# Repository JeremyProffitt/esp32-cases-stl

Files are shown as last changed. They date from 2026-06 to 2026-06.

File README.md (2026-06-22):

# ESP32 Cases (OpenSCAD / STL)

OpenSCAD designs for 3D-printable ESP32 device enclosures.

Generated STL and PNG artifacts are **not committed** — they are produced by
the build scripts and attached to [GitHub Releases](https://github.com/JeremyProffitt/esp32-cases-stl/releases/latest).

## Building locally

Requires [OpenSCAD](https://openscad.org/). Then:

```bash
./build.sh        # Linux / macOS
build.bat         # Windows
```

This renders an STL plus front/rear PNGs for **every** `.scad` in the repo into
`build/`.

---

## Designs

### TTGO-TM ESP32 ("TMusic") Enclosure

A two-part enclosure for a TTGO-TM ESP32 music device: a **base tray** (the
deep box that holds the PCB) and a **front bezel** (the face with the display
window, speaker/finger slots, button hole and side ports). Footprint
76.2 × 49.5 mm.

Each part is provided in **two forms**:

- **Mesh wrapper** (`*_mesh.scad`) — imports the original CATIA-exported STL
  verbatim. **Geometry-exact**; use for final prints / fit checks.
- **Parametric rebuild** (`ttgo_body.scad`, `ttgo_cap.scad`) — hand-modelled
  from OpenSCAD primitives. **Editable but approximate**; use to tweak
  dimensions.

Folder: [`TTGO-TM-ESP32-aka-TMusic/`](TTGO-TM-ESP32-aka-TMusic/)

#### Drawing diagrams

Dimensioned multi-view (front / top / right / isometric) engineering sheets,
generated from the parametric models by [`tools/make_drawings.py`](tools/make_drawings.py):

| Base Tray | Front Bezel |
|---|---|
| Tray drawing | Bezel drawing |

#### Base Tray — parametric (`ttgo_cap.scad`)

| Front View | Rear View |
|---|---|
| Front | Rear |

**Documentation**: [ttgo_cap.md](TTGO-TM-ESP32-aka-TMusic/ttgo_cap.md)
· **Download STL**: [ttgo_cap.stl](https://github.com/JeremyProffitt/esp32-cases-stl/releases/latest/download/ttgo_cap.stl)

#### Base Tray — exact mesh (`ttgo_cap_mesh.scad`)

| Front View | Rear View |
|---|---|
| Front | Rear |

**Documentation**: [ttgo_cap_mesh.md](TTGO-TM-ESP32-aka-TMusic/ttgo_cap_mesh.md)
· **Download STL**: [ttgo_cap_mesh.stl](https://github.com/JeremyProffitt/esp32-cases-stl/releases/latest/download/ttgo_cap_mesh.stl)

#### Front Bezel — parametric (`ttgo_body.scad`)

| Front View | Rear View |
|---|---|
| Front | Rear |

**Documentation**: [ttgo_body.md](TTGO-TM-ESP32-aka-TMusic/ttgo_body.md)
· **Download STL**: [ttgo_body.stl](https://github.com/JeremyProffitt/esp32-cases-stl/releases/latest/download/ttgo_body.stl)

#### Front Bezel — exact mesh (`ttgo_body_mesh.scad`)

| Front View | Rear View |
|---|---|
| Front | Rear |

**Documentation**: [ttgo_body_mesh.md](TTGO-TM-ESP32-aka-TMusic/ttgo_body_mesh.md)
· **Download STL**: [ttgo_body_mesh.stl](https://github.com/JeremyProffitt/esp32-cases-stl/releases/latest/download/ttgo_body_mesh.stl)

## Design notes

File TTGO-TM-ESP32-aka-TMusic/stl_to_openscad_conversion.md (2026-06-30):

# STL To OpenSCAD Conversion Notes

## Purpose

This document records how the TTGO-TM ESP32 ("TMusic") STL files in this folder
were converted into editable OpenSCAD approximations.

The goal was not to reproduce every triangle. STL files do not contain the
original CAD feature tree, sketch constraints, or boolean history. The practical
goal was to identify the functional envelope, openings, cavities, lips, rims,
and support features, then rebuild them with clean named OpenSCAD primitives.

## Files Converted

| Source STL | New Parametric SCAD | Functional Name |
|---|---|---|
| `ttgo-body-2.stl` | `ttgo_body.scad` | `ttgo_top_bezel()` |
| `ttgo-cap-2.stl` | `ttgo_cap.scad` | `ttgo_base_tray()` |

Backward-compatible module names were retained:

- `ttgo_body()` calls `ttgo_top_bezel()`.
- `ttgo_cap()` calls `ttgo_base_tray()`.

## Guidance Used

The process followed `C:\dev\esp32-cases-stl\CLAUDE.md`:

- Document the coordinate system at the top of each SCAD file.
- Use named `*_mm` constants for all measurements.
- Keep each component or cutout in its own module.
- Include a component index table.
- Add module comments with position, bounding box, alignment, and connection
  notes.
- Provide connection interface functions.
- Provide debug and validation modules.
- Keep matching Markdown documentation next to each SCAD file.

## Measurement Method

The STLs were inspected with Python `trimesh` and section plots:

```powershell
python - <<'PY'
import trimesh
for file in ["ttgo-body-2.stl", "ttgo-cap-2.stl"]:
    mesh = trimesh.load_mesh(file, process=True)
    print(file, len(mesh.faces), mesh.bounds, mesh.extents, mesh.is_watertight)
PY
```

Additional XY section images were generated at representative Z heights and
saved in `analysis_slices/`.

Measured source facts:

| Part | Faces | Native min [X,Y,Z] | Native max [X,Y,Z] | Size [W,D,H] |
|---|---|---|---|---|
| Top bezel | 51,684 | [-36.675, -44.4235, -3.540] | [39.525, 5.1000, 11.460] | [76.200, 49.5235, 15.000] |
| Base tray | 54,112 | [-36.675, -44.4235, -20.290] | [39.525, 5.1000, 1.860] | [76.200, 49.5235, 22.150] |

The earlier mesh Markdown had the face counts swapped; the docs now reflect the
actual loaded files.

## Coordinate Normalization

The original CATIA-exported meshes use native coordinates with the origin inside
or near the assembly. The parametric SCAD files use the project convention:

```text
X = width
Y = depth
Z = height
Origin = front-left-bottom corner of each normalized part
```

Normalization is:

```text
normalized_point = native_point - source_bbox_min
```

The validation modules reverse this by importing the STL and applying:

```openscad
translate(-source_*_bbox_min_mm)
    import(source_*_mesh_file, convexity = 10);
```

## Reconstruction Strategy

Each part was rebuilt using the same pattern:

1. Start with a positive rounded rectangular bounding block matching the STL
   length, width, and height.
2. Subtract named negative cutouts for cavities and openings.
3. Add positive support features only when they are functional and visible in
   multiple sections.
4. Preserve the exact STL import as a validation overlay, not as the default
   model.

This makes the SCAD files readable as manufacturing recipes instead of opaque
polyhedron dumps.

## Top Bezel Feature Decisions

The top bezel was rebuilt around these named features:

- `top_bezel_positive_shell()`: full `76.2 x 49.523 x 15 mm` rounded shell.
- `top_bezel_inner_cavity_cutout()`: underside cavity leaving a 3 mm top face.
- `top_bezel_display_window_cutout()`: large display aperture measured from
  high-Z sections, about `51.5 x 38.4 mm`.
- `top_bezel_side_control_slot_cutouts()`: four rounded rectangular openings.
- `top_bezel_corner_relief_hole_cutouts()`: four small 1.9 mm holes near the
  top-face corners.
- `top_bezel_skirt_alignment_relief_cutouts()`: small inside-wall lower skirt
  reliefs, now starting 3 mm above the bezel bottom.

Important correction: the previous approximation used five narrow slots. The
source mesh sections show four larger rounded slots, so the rebuild uses four.

## Base Tray Feature Decisions

The base tray was rebuilt around these named features:

- `base_tray_outer_block()`: full `76.2 x 49.523 x 22.15 mm` rounded shell.
- `base_tray_inner_cavity_cutout()`: main electronics cavity, starting above a
  1.75 mm floor.
- `base_tray_rim_rabbet_cutout()`: top perimeter rabbet, approximately 5.4 mm
  high, used by the bezel skirt.
- `base_tray_support_lugs_positive()`: four discrete lugs near the upper rim.
- `base_tray_snap_tabs_positive()`: positive tabs on the tray lip that align
  with the bezel's inside-wall snap relief pockets.
- `base_tray_left_wall_connector_relief_cutouts()`: two left-wall reliefs at
  the upper rim.

Important correction: the previous approximation used continuous PCB rails. The
source sections show discrete support/lug blocks, so the rebuild models those
instead.

## Validation Performed

OpenSCAD was found at:

```text
C:\Program Files\OpenSCAD\openscad.exe
```

Both files were exported through OpenSCAD:

```powershell
& 'C:\Program Files\OpenSCAD\openscad.exe' -o .\build\ttgo_body_test.stl .\ttgo_body.scad
& 'C:\Program Files\OpenSCAD\openscad.exe' -o .\build\ttgo_cap_test.stl .\ttgo_cap.scad
```

The generated STL files were then checked with `trimesh`:

| Generated STL | Watertight | Connected Components | Extents |
|---|---|---|---|
| `build/ttgo_body_test.stl` | yes | 1 | [76.2, 49.523, 15.0] |
| `build/ttgo_cap_test.stl` | yes | 1 | [76.2, 49.523, 22.15] |

Preview PNGs were also rendered with OpenSCAD:

```powershell
& 'C:\Program Files\OpenSCAD\openscad.exe' --autocenter --viewall --imgsize=1200,900 --camera=0,0,0,55,0,45,0 -o .\build\ttgo_body_preview.png .\ttgo_body.scad
& 'C:\Program Files\OpenSCAD\openscad.exe' --autocenter --viewall --imgsize=1200,900 --camera=0,0,0,55,0,45,0 -o .\build\ttgo_cap_preview.png .\ttgo_cap.scad
```

## How To Inspect In OpenSCAD

Open either file in OpenSCAD:

- `ttgo_body.scad`
- `ttgo_cap.scad`

At the bottom of each SCAD file, use:

```openscad
see_in_color = 1; // colored manual preview
```

Primary display toggle:

| Variable | Meaning |
|---|---|
| `see_in_color = 0` | Printable model view and STL export; forced by `build.sh` and `build.bat` |
| `see_in_color = 1` | Default manual view; color-coded positive/support/cutout preview for OpenSCAD Preview/F5 |

Advanced debug modes are available through `debug_view_mode` when
`see_in_color = 0`:

| Mode | Meaning |
|---|---|
| `"model"` | Default rebuilt parametric part for printable STL export |
| `"overlay"` | Rebuilt part over the normalized source STL |
| `"cutouts"` | Positive shell plus visible negative volumes |
| `"positive"` | Positive starting geometry only |
| `"section_x"` | Thin X section |
| `"section_y"` | Thin Y section |

## Remaining Judgment Calls

The following details should be verified against the real board before final
printing:

- Whether the four small top holes are screw holes, locating holes, or reliefs.
- Exact connector clearance needs on the left wall and lower skirt.
- Whether the support lugs should be widened or lowered for the actual PCB.
- Preferred fit clearance between the bezel skirt and base tray rim.

## Summary

The final SCAD files are now editable constructive models instead of mesh
imports or polyhedron dumps. The source STLs remain available through the mesh
wrapper files for exact reference and overlay validation.

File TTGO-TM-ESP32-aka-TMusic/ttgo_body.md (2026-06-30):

# TTGO-TM ESP32 ("TMusic") - Top / Front Bezel

## Overview

`ttgo_body.scad` is an editable, constructive OpenSCAD rebuild of
`ttgo-body-2.stl`. It is not a triangle-exact copy. The source STL remains the
fit-check reference; this model turns the measured STL envelope and visible
openings into named positive and negative primitives.

The model starts with a positive rounded bounding shell and removes named
negative cutouts for the underside cavity, display window, four side control
slots, four small corner relief holes, and skirt alignment reliefs.

## Source Mesh

| Property | Value |
|---|---|
| File | `ttgo-body-2.stl` |
| Faces | 51,684 |
| Native min [X,Y,Z] mm | [-36.675, -44.4235, -3.540] |
| Native max [X,Y,Z] mm | [39.525, 5.1000, 11.460] |
| Normalized size [W,D,H] mm | [76.200, 49.5235, 15.000] |

The SCAD file uses normalized corner-origin coordinates. The validation overlay
imports the mesh and translates it by `-source_body_bbox_min_mm`.

## Coordinate System

```text
X = Width  (positive = right)
Y = Depth  (positive = back/away from viewer)
Z = Height (positive = up)

Origin: front-left-bottom corner of the normalized bezel bounding box.
```

## Dimensions

| Parameter | Value | Description |
|---|---|---|
| **Source** | | |
| source_body_face_count | 51684 | STL face count from `trimesh` and OpenSCAD import checks |
| source_body_bbox_size_mm | [76.200, 49.5235, 15.000] | Mesh bounding-box size |
| **Global / Shared** | | |
| case_width_mm | 76.200 | Overall X envelope |
| case_depth_mm | 49.523 | Overall Y envelope |
| case_corner_radius_mm | 2.300 | Clean outer corner radius |
| case_inner_corner_radius_mm | 1.300 | Inner cavity corner radius |
| case_wall_thickness_mm | 2.500 | Nominal wall thickness target |
| case_fit_clearance_xy_mm | 0.250 | Named fit allowance for mating interfaces |
| case_epsilon_mm | 0.050 | Boolean anti-coincident-face offset |
| **top_bezel_positive_shell** | | |
| top_bezel_height_mm | 15.000 | Overall Z height |
| top_bezel_face_thickness_mm | 3.000 | Top face plate thickness |
| top_bezel_skirt_height_mm | 12.000 | Lower skirt height |
| **top_bezel_inner_cavity_cutout** | | |
| top_bezel_inner_cavity_x_mm | 2.900 | Cavity X origin |
| top_bezel_inner_cavity_y_mm | 2.400 | Cavity Y origin |
| top_bezel_inner_cavity_width_mm | 70.400 | Cavity X size |
| top_bezel_inner_cavity_depth_mm | 44.700 | Cavity Y size |
| **top_bezel_display_window_cutout** | | |
| display_window_x_mm | 15.200 | Window X origin |
| display_window_y_mm | 5.600 | Window Y origin |
| display_window_width_mm | 51.500 | Window X size |
| display_window_depth_mm | 38.400 | Window Y size |
| display_window_corner_radius_mm | 0.800 | Clean corner radius |
| **top_bezel_side_control_slot_cutouts** | | |
| side_control_slot_count | 4 | Number of rounded side slots observed in top slices |
| side_control_slot_x_mm | 2.750 | Slot X origin |
| side_control_slot_first_y_mm | 12.100 | First slot Y origin |
| side_control_slot_pitch_mm | 7.600 | Y pitch |
| side_control_slot_width_mm | 8.700 | Slot X size |
| side_control_slot_depth_mm | 5.900 | Slot Y size |
| side_control_slot_radius_mm | 2.700 | Slot end radius |
| **top_bezel_corner_relief_hole_cutouts** | | |
| corner_relief_hole_diameter_mm | 1.900 | Small relief hole diameter |
| corner_relief_hole_left_x_mm / right_x_mm | 6.200 / 70.850 | Hole X centers |
| corner_relief_hole_front_y_mm / back_y_mm | 5.300 / 44.350 | Hole Y centers |
| **top_bezel_skirt_alignment_relief_cutouts** | | |
| skirt_relief_width_mm | 8.000 | Front/back skirt notch width |
| skirt_relief_depth_mm | 1.400 | Front/back skirt notch depth |
| skirt_relief_height_mm | 2.500 | Lower skirt notch height |
| skirt_relief_z_mm | 3.000 | Relief bottom height above bezel bottom |

## Color Key

`see_in_color` defaults to `1` in `ttgo_body.scad`, so OpenSCAD Preview (`F5`)
shows the shell and cutout volumes by color when the file is opened manually.
Set `see_in_color = 0` for the printable boolean result; the project build
scripts force that value for generated STL/PNG artifacts. The cutouts are voids
in the printable model, so they cannot remain separately colored. Colors are
preview aids only; exported STL files do not retain them.

| Color | Section Name | Meaning |
|---|---|---|
| Gold | `top_bezel_positive_shell` | Starting positive bezel body |
| Dodger blue | `top_bezel_inner_cavity_cutout` | Underside hollow cavity removed from the shell |
| Lime green | `top_bezel_display_window_cutout` | Display window through-cut |
| Magenta | `top_bezel_side_control_slot_cutouts` | Four side control / access slots |
| Red | `top_bezel_corner_relief_hole_cutouts` | Four small corner relief holes |
| Cyan | `top_bezel_skirt_alignment_relief_cutouts` | Inside-wall lower skirt and side relief notches |
| Orange | `validation_source_mesh` | Source STL overlay in validation mode |

## Component Diagram

### Top View (looking down, -Z)

```text
        +Y (back)
           ^
    +--o---------------------------o--+
    | [slot]  +-------------------+   |
    | [slot]  |                   |   |
    | [slot]  |   display window  |   |
    | [slot]  |                   |   |
    |         +-------------------+   |
    +--o---------------------------o--+ --> +X
   /
  Origin [0,0]
```

### Side View (looking from right, -X)

```text
        +Z
         ^
    +----+------------------+  top face with window/slots/holes
    |                       |
    |       hollow skirt    |
    |                       |
    +---[small reliefs]-----+ --> +Y
   z=0
```

## Components

### top_bezel_positive_shell

- Purpose: Main printable mass of the top/front bezel.
- Position: Origin `[0,0,0]`.
- Bounding box: `[0,0,0]` to `[76.2,49.523,15]`.
- Construction: Rounded rectangular prism.

### top_bezel_inner_cavity_cutout

- Purpose: Opens the underside while preserving a 3 mm top face.
- Position: `[2.9,2.4,-0.05]`.
- Bounding box: approximately `[2.9,2.4,-0.05]` to `[73.3,47.1,12.05]`.

### top_bezel_display_window_cutout

- Purpose: Main display aperture.
- Position: `[15.2,5.6,11.95]`.
- Bounding box: approximately `[15.2,5.6,11.95]` to `[66.7,44.0,15.55]`.

### top_bezel_side_control_slot_cutouts

- Purpose: Four rounded rectangular side openings visible in upper mesh
  cross-sections.
- Position: left-side top face region.
- Approximate slot size: `[8.7,5.9,thru]`.

### top_bezel_corner_relief_hole_cutouts

- Purpose: Four small holes near the top-face corners. They are named
  generically because the STL does not reveal whether they are screw,
  locating, or manufacturing relief features.
- Diameter: `1.9 mm`.

### top_bezel_skirt_alignment_relief_cutouts

- Purpose: Small internal notches in the lower skirt and left slot wall region.
- Position: inside faces of the lower skirt walls, starting 3 mm above the
  bezel bottom.

## Debug And Validation Modules

| Module | Purpose |
|---|---|
| `debug_axes(length_mm)` | Shows RGB XYZ axes |
| `debug_bounds()` | Shows normalized bounding box |
| `debug_positive_only()` | Shows the starting positive shell |
| `debug_negative_only()` | Shows all cutout volumes |
| `debug_cutouts()` | Overlays positive shell and negative volumes |
| `color_key_preview()` | Shows the named color key geometry |
| `debug_section_x(x_mm)` | Thin X section |
| `debug_section_y(y_mm)` | Thin Y section |
| `validation_source_mesh()` | Imports and normalizes the source STL |
| `validation_overlay()` | Overlays rebuild and source mesh |
| `assembly_colored()` | Colored part view |
| `assembly_exploded(separation_mm)` | Exploded-position helper |

## Assembly Notes

- Mates with `ttgo_cap.scad` / `ttgo_base_tray()`.
- The original mesh and rebuild should be compared with `validation_overlay()`
  before printing.
- Print orientation depends on whether face quality or support avoidance matters
  more. Face-down gives a cleaner visible face; skirt-down reduces top-face bed
  contact marks but may need support for openings.
- Recommended material: PLA or PETG.

## Known Approximations

- Organic CATIA fillets were simplified to clean rounded rectangles.
- The four side slots are modeled from slice measurements rather than recovered
  CAD history.
- The lower skirt reliefs are functional approximations of repeated mesh edge
  breaks.

## Changelog

| Date | Change |
|---|---|
| 2026-06-30 | Rebuilt as explicit positive shell plus named negative cutouts; corrected slot count to four; added validation modules |

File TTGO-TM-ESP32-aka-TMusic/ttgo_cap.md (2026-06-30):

# TTGO-TM ESP32 ("TMusic") - Base Tray

## Overview

`ttgo_cap.scad` is an editable, constructive OpenSCAD rebuild of
`ttgo-cap-2.stl`. The source file name says "cap", but the part is the deep
base tray that holds the electronics and accepts the top/front bezel.

The model starts from the full positive bounding block, removes the main cavity
and rim rabbet as named negative cutouts, then adds discrete support/lug blocks
near the upper inner rim.

## Source Mesh

| Property | Value |
|---|---|
| File | `ttgo-cap-2.stl` |
| Faces | 54,112 |
| Native min [X,Y,Z] mm | [-36.675, -44.4235, -20.290] |
| Native max [X,Y,Z] mm | [39.525, 5.1000, 1.860] |
| Normalized size [W,D,H] mm | [76.200, 49.5235, 22.150] |

The SCAD file uses normalized corner-origin coordinates. The validation overlay
imports the mesh and translates it by `-source_cap_bbox_min_mm`.

## Coordinate System

```text
X = Width  (positive = right)
Y = Depth  (positive = back/away from viewer)
Z = Height (positive = up)

Origin: front-left-bottom corner of the normalized tray bounding box.
```

## Dimensions

| Parameter | Value | Description |
|---|---|---|
| **Source** | | |
| source_cap_face_count | 54112 | STL face count from `trimesh` and OpenSCAD import checks |
| source_cap_bbox_size_mm | [76.200, 49.5235, 22.150] | Mesh bounding-box size |
| **Global / Shared** | | |
| case_width_mm | 76.200 | Overall X envelope |
| case_depth_mm | 49.523 | Overall Y envelope |
| case_corner_radius_mm | 2.300 | Clean outer corner radius |
| case_inner_corner_radius_mm | 0.800 | Inner cavity corner radius |
| case_wall_thickness_mm | 2.500 | Nominal wall thickness target |
| case_fit_clearance_xy_mm | 0.250 | Per-side fit clearance |
| case_fit_clearance_z_mm | 0.200 | Seating clearance |
| case_epsilon_mm | 0.050 | Boolean anti-coincident-face offset |
| **base_tray_outer_block** | | |
| base_tray_height_mm | 22.150 | Overall tray height |
| base_tray_floor_thickness_mm | 1.750 | Floor thickness inferred from low-Z sections |
| **base_tray_inner_cavity_cutout** | | |
| base_tray_inner_cavity_x_mm | 5.250 | Cavity X origin |
| base_tray_inner_cavity_y_mm | 4.250 | Cavity Y origin |
| base_tray_inner_cavity_width_mm | 66.700 | Cavity X size |
| base_tray_inner_cavity_depth_mm | 41.000 | Cavity Y size |
| **base_tray_rim_rabbet_cutout** | | |
| base_tray_rim_height_mm | 5.400 | Upper rim/rabbet height |
| base_tray_rim_inset_x_mm | 3.700 | Inset rim X origin |
| base_tray_rim_inset_y_mm | 2.700 | Inset rim Y origin |
| base_tray_rim_width_mm | 69.800 | Inset rim X size |
| base_tray_rim_depth_mm | 44.100 | Inset rim Y size |
| **support_lugs** | | |
| support_lug_z_mm | 18.100 | Lug bottom Z |
| support_lug_height_mm | 3.300 | Lug height |
| support_lug_depth_mm | 2.200 | Lug Y protrusion |
| front_support_lug_specs_mm | [[13.8,14.2],[49.0,14.2]] | Front-side lug X origins and widths |
| rear_support_lug_specs_mm | [[23.8,6.4],[56.0,8.5]] | Rear-side lug X origins and widths |
| **base_tray_snap_tabs_positive** | | |
| snap_tab_relief_z_from_bezel_bottom_mm | 3.000 | Matching height of the bezel relief pockets |
| snap_tab_z_mm | 19.750 | Tab bottom Z on the tray rim |
| snap_tab_height_mm | 2.350 | Tab height after fit/top-clearance limiting |
| snap_tab_width_mm | 7.700 | Front/back tab X size with clearance |
| snap_tab_depth_mm | 1.250 | Front/back tab protrusion with clearance |
| snap_tab_left_width_mm | 1.650 | Left tab X protrusion with clearance |
| snap_tab_left_depth_mm | 3.500 | Left tab Y size with clearance |
| **base_tray_left_wall_connector_relief_cutouts** | | |
| left_wall_relief_centers_y_mm | [18.2,36.8] | Y centers for left wall reliefs |
| left_wall_relief_width_mm | 4.000 | X cut depth through left wall |
| left_wall_relief_depth_mm | 7.200 | Y relief size |
| left_wall_relief_height_mm | 8.500 | Z relief size |

## Color Key

`see_in_color` defaults to `1` in `ttgo_cap.scad`, so OpenSCAD Preview (`F5`)
shows the shell, support lugs, snap tabs, and cutout volumes by color when the
file is opened manually. Set `see_in_color = 0` for the printable boolean
result; the project build scripts force that value for generated STL/PNG
artifacts. The cutouts are voids in the printable model, so they cannot remain
separately colored. The magenta support lugs and cyan snap tabs are lifted
upward only in this preview mode so they are not hidden by the rim/cutout
volumes. Colors are preview aids only; exported STL files do not retain them.

| Color | Section Name | Meaning |
|---|---|---|
| Gold | `base_tray_outer_block` | Starting positive tray body |
| Dodger blue | `base_tray_inner_cavity_cutout` | Main electronics cavity removed from the tray |
| Lime green | `base_tray_rim_rabbet_cutout` | Rim rabbet removed to form the bezel seat |
| Magenta | `base_tray_support_lugs_positive` | Positive support / latch / PCB-location lugs |
| Cyan | `base_tray_snap_tabs_positive` | Positive snap tabs that fit the bezel inside-wall relief pockets |
| Red | `base_tray_left_wall_connector_relief_cutouts` | Upper left-wall connector relief cutouts |
| Orange | `validation_source_mesh` | Source STL overlay in validation mode |

## Component Diagram

### Top View (looking down, -Z, into the open tray)

```text
        +Y (back)
           ^
    +------+---------------------------+
    |     [rear lug]        [rear lug] |
    |  +-----------------------------+ |
    |  |                             | |
    |  |        inner cavity         | |
    |  |                             | |
    |  +-----------------------------+ |
    |   [front lug]       [front lug]  |
    +--[relief]-----------[relief]-----+ --> +X
   /
  Origin [0,0]
```

### Side View (looking from right, -X)

```text
        +Z
         ^
    +----+---------+  inset upper rim / rabbet
    |    cavity    |
    |              |
    |              |
    +--------------+
    |    floor     |
    +--------------+ --> +Y
   z=0
```

## Components

### base_tray_outer_block

- Purpose: Overall positive rounded bounding block.
- Position: Origin `[0,0,0]`.
- Bounding box: `[0,0,0]` to `[76.2,49.523,22.15]`.

### base_tray_inner_cavity_cutout

- Purpose: Main hollow electronics volume.
- Position: `[5.25,4.25,1.75]`.
- Bounding box: approximately `[5.25,4.25,1.75]` to `[71.95,45.25,22.65]`.

### base_tray_rim_rabbet_cutout

- Purpose: Removes the outer top ring to form the inset ledge that receives
  the bezel skirt.
- Z range: approximately `[16.75,22.15]`.
- Functional interface: `base_tray_rim_seat_size_mm()`.

### base_tray_support_lugs_positive

- Purpose: Four discrete support/latch/PCB-locating pads near the upper rim.
- Z range: `[18.1,21.4]`.
- These replace the earlier single continuous rail approximation.

### base_tray_snap_tabs_positive

- Purpose: Positive snap tabs on the tray lip that fit into the cyan
  inside-wall relief pockets in `ttgo_body.scad`.
- Position: front, back, and left rim lips.
- Z range: approximately `[19.75,22.10]`, matching relief pockets that start
  3 mm above the seated bezel bottom.
- Fit: tabs are slightly smaller than the bezel pockets using
  `snap_tab_clearance_xy_mm` and `snap_tab_clearance_z_mm`.

### base_tray_left_wall_connector_relief_cutouts

- Purpose: Two upper left-wall reliefs visible in high-Z source sections.
- These are modeled as clean rectangular cutouts because the STL does not
  expose original CAD feature history.

## Debug And Validation Modules

| Module | Purpose |
|---|---|
| `debug_axes(length_mm)` | Shows RGB XYZ axes |
| `debug_bounds()` | Shows normalized bounding box |
| `debug_positive_only()` | Shows the outer block plus lug positives |
| `debug_negative_only()` | Shows all cutout volumes |
| `debug_cutouts()` | Overlays positive and negative volumes |
| `color_key_preview()` | Shows the named color key geometry |
| `debug_section_x(x_mm)` | Thin X section |
| `debug_section_y(y_mm)` | Thin Y section |
| `validation_source_mesh()` | Imports and normalizes the source STL |
| `validation_overlay()` | Overlays rebuild and source mesh |
| `assembly_colored()` | Colored part view |
| `assembly_exploded(separation_mm)` | Exploded-position helper |

## Assembly Notes

- Mates with `ttgo_body.scad` / `ttgo_top_bezel()`.
- The rim seat includes named XY and Z clearances rather than hidden offsets.
- Print orientation: floor down, open mouth up.
- Recommended material: PLA or PETG.

## Known Approximations

- CATIA fillets and small organic transitions are simplified to clean radii.
- The rim/lug geometry is modeled from mesh slices, not recovered CAD history.
- Connector reliefs are named functionally but should be verified against the
  physical board before relying on them for final connector clearance.

## Changelog

| Date | Change |
|---|---|
| 2026-06-30 | Rebuilt as explicit constructive tray with rim rabbet, discrete support lugs, named reliefs, and validation modules |

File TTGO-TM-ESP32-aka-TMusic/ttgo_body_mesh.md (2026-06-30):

# TTGO-TM ESP32 ("TMusic") — Front Bezel (Mesh / Import Wrapper)

## Overview

Exact reproduction of the front bezel. [`ttgo_body_mesh.scad`](ttgo_body_mesh.scad)
imports the original CATIA-exported mesh **`ttgo-body-2.stl`** verbatim via
OpenSCAD's `import()`, so the geometry is 100 % faithful to the source part.

Use this file when you need the real geometry (final print, accurate fit
checks). For an editable parametric approximation, see
[`ttgo_body.scad`](ttgo_body.md).

> The source mesh must sit beside the `.scad` file (it does, in this folder).

## Source Mesh

| Property | Value |
|---|---|
| File | `ttgo-body-2.stl` |
| Generator | "STL generated by Digitized Shape Editor / CATIA" |
| Triangles | 51,684 |
| Min [X,Y,Z] mm | [-36.675, -44.423, -3.540] |
| Max [X,Y,Z] mm | [ 39.525, 5.100, 11.460] |
| Size [W,D,H] mm | [ 76.200, 49.523, 15.000] |

The mesh origin is interior to the part (CATIA digitised-shape origin), not at
a corner.

## Modules

| Module | Purpose |
|---|---|
| `ttgo_body_mesh()` | Import the bezel mesh as-is |
| `debug_axes(length)` | XYZ axes at origin |
| `debug_bounds()` | Transparent bounding box |
| `debug_recenter()` | Same mesh shifted so bbox-min sits at the origin |

## Notes

- `convexity = 10` is set so the preview renders correctly through the
  bezel's openings.
- Native coordinates are shared with `ttgo_cap_mesh.scad`; importing both in
  native coords shows them already mated.

## Changelog

| Date | Change |
|---|---|
| 2026-06-22 | Initial import wrapper for ttgo-body-2.stl |

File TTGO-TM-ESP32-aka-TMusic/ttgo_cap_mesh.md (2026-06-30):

# TTGO-TM ESP32 ("TMusic") — Base Tray (Mesh / Import Wrapper)

## Overview

Exact reproduction of the base tray. [`ttgo_cap_mesh.scad`](ttgo_cap_mesh.scad)
imports the original CATIA-exported mesh **`ttgo-cap-2.stl`** verbatim via
OpenSCAD's `import()`, so the geometry is 100 % faithful to the source part.

> **Naming note:** the source file is called *cap*, but the part is the deep
> **base tray**, not a lid.

Use this file when you need the real geometry. For an editable parametric
approximation, see [`ttgo_cap.scad`](ttgo_cap.md).

> The source mesh must sit beside the `.scad` file (it does, in this folder).

## Source Mesh

| Property | Value |
|---|---|
| File | `ttgo-cap-2.stl` |
| Generator | "STL generated by Digitized Shape Editor / CATIA" |
| Triangles | 54,112 |
| Min [X,Y,Z] mm | [-36.675, -44.423, -20.290] |
| Max [X,Y,Z] mm | [ 39.525, 5.100, 1.860] |
| Size [W,D,H] mm | [ 76.200, 49.523, 22.150] |

## Modules

| Module | Purpose |
|---|---|
| `ttgo_cap_mesh()` | Import the tray mesh as-is |
| `debug_axes(length)` | XYZ axes at origin |
| `debug_bounds()` | Transparent bounding box |
| `debug_recenter()` | Same mesh shifted so bbox-min sits at the origin |
| `assembly_mesh()` | Tray + bezel meshes shown together in native coords |

## Notes

- `convexity = 10` is set so the preview renders correctly through the deep
  cavity.
- The cap (z −20.29 … 1.86) and the body (z −3.54 … 11.46) share the same X/Y
  datum and overlap near z ≈ 0, so `assembly_mesh()` shows the closed
  enclosure.

## Changelog

| Date | Change |
|---|---|
| 2026-06-22 | Initial import wrapper for ttgo-cap-2.stl |

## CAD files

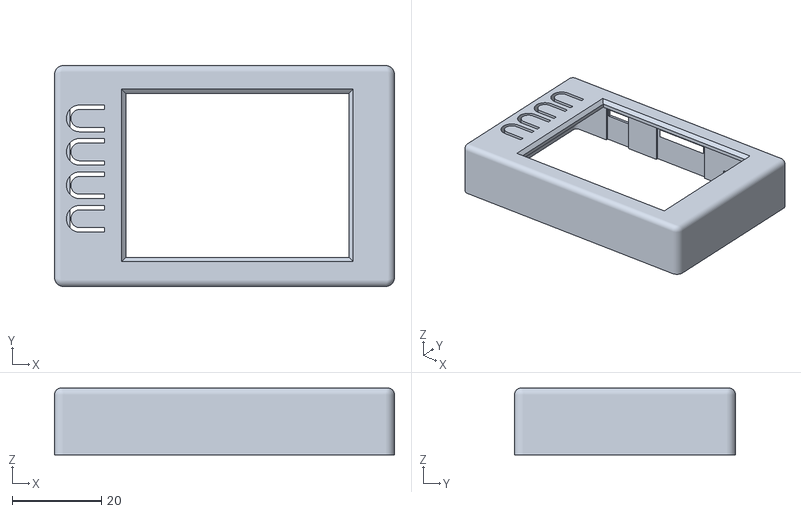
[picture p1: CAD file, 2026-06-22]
TTGO-TM-ESP32-aka-TMusic/ttgo-body-2.stl
76.2 x 49.5 x 15.0

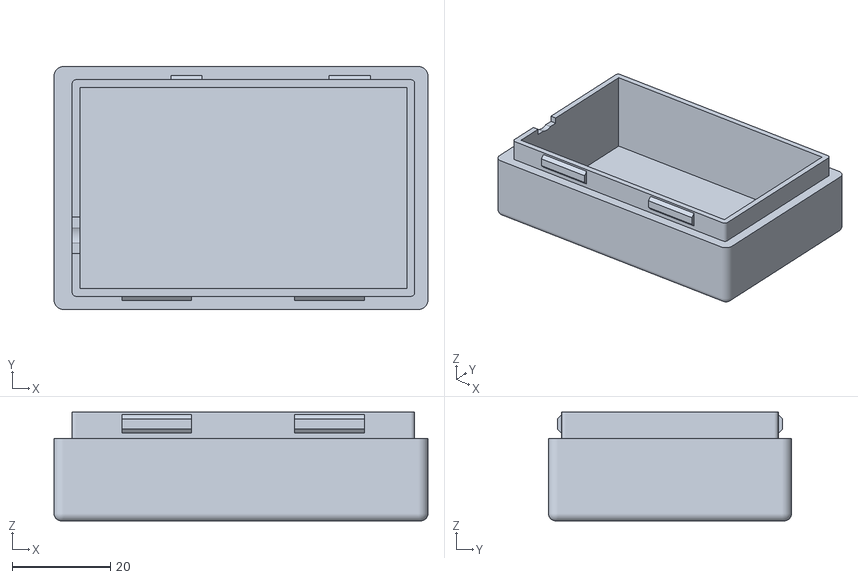
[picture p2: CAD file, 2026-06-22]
TTGO-TM-ESP32-aka-TMusic/ttgo-cap-2.stl
76.2 x 49.5 x 22.2

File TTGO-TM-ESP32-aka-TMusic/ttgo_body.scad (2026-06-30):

/**
 * TTGO-TM ESP32 ("TMusic") - TOP / FRONT BEZEL
 * Parametric constructive rebuild from ttgo-body-2.stl.
 *
 * This is an editable approximation, not a triangle-for-triangle copy. The
 * source STL is kept as the reference mesh. The model is built from one
 * positive rounded bounding shell and named negative cutouts for the functional
 * openings observed in mesh cross-sections.
 *
 * Coordinate System:
 *   X = Width  (positive = right)
 *   Y = Depth  (positive = back/away from viewer)
 *   Z = Height (positive = up)
 *
 * Origin: Front-left-bottom corner of the normalized bezel bounding box.
 *
 * ===========================================
 * COMPONENT INDEX
 * ===========================================
 *
 * | Component                    | Preview Color | Origin [X,Y,Z] | Size [W,D,H]       | Attaches To      |
 * |------------------------------|---------------|----------------|--------------------|------------------|
 * | top_bezel_positive_shell     | gold          | [0,0,0]        | [76.2,49.523,15]   | base tray rim    |
 * | top_bezel_inner_cavity       | dodgerblue    | [2.9,2.4,0]    | [70.4,44.7,12.05]  | negative cutout  |
 * | display_window               | limegreen     | [15.2,5.6,12]  | [51.5,38.4,thru]   | negative cutout  |
 * | side_control_slots (x4)      | magenta       | left face area | [8.7,5.9,thru]     | negative cutout  |
 * | corner_relief_holes (x4)     | red           | top corners    | d=1.9              | negative cutout  |
 * | skirt_alignment_reliefs      | cyan          | inside skirt walls | variable        | negative cutout  |
 */

// ===========================================
// DIMENSIONS (all values in millimeters)
// ===========================================

// --- Source mesh facts ---
source_body_mesh_file = "ttgo-body-2.stl";
source_body_bbox_min_mm = [-36.675, -44.4235, -3.540];
source_body_bbox_max_mm = [ 39.525,   5.1000, 11.460];
source_body_bbox_size_mm = [76.200, 49.5235, 15.000];
source_body_face_count = 51684;

// --- Global / shared case dimensions ---
case_width_mm = 76.200;
case_depth_mm = 49.523;
case_corner_radius_mm = 2.300;
case_inner_corner_radius_mm = 1.300;
case_wall_thickness_mm = 2.500;
case_fit_clearance_xy_mm = 0.250;
case_epsilon_mm = 0.050;
case_cut_overshoot_mm = 0.500;

// --- top_bezel_positive_shell dimensions ---
top_bezel_height_mm = 15.000;
top_bezel_face_thickness_mm = 3.000;
top_bezel_skirt_height_mm = top_bezel_height_mm - top_bezel_face_thickness_mm;

// --- top_bezel_inner_cavity_cutout dimensions ---
top_bezel_inner_cavity_x_mm = 2.900;
top_bezel_inner_cavity_y_mm = 2.400;
top_bezel_inner_cavity_width_mm = 70.400;
top_bezel_inner_cavity_depth_mm = 44.700;
top_bezel_inner_cavity_height_mm = top_bezel_skirt_height_mm + case_epsilon_mm;

// --- top_bezel_display_window_cutout dimensions ---
display_window_x_mm = 15.200;
display_window_y_mm = 5.600;
display_window_width_mm = 51.500;
display_window_depth_mm = 38.400;
display_window_corner_radius_mm = 0.800;

// --- top_bezel_side_control_slot_cutouts dimensions ---
side_control_slot_count = 4;
side_control_slot_x_mm = 2.750;
side_control_slot_first_y_mm = 12.100;
side_control_slot_pitch_mm = 7.600;
side_control_slot_width_mm = 8.700;
side_control_slot_depth_mm = 5.900;
side_control_slot_radius_mm = 2.700;

// --- top_bezel_corner_relief_hole_cutouts dimensions ---
corner_relief_hole_diameter_mm = 1.900;
corner_relief_hole_left_x_mm = 6.200;
corner_relief_hole_right_x_mm = 70.850;
corner_relief_hole_front_y_mm = 5.300;
corner_relief_hole_back_y_mm = 44.350;

// --- top_bezel_skirt_alignment_relief_cutouts dimensions ---
skirt_relief_width_mm = 8.000;
skirt_relief_depth_mm = 1.400;
skirt_relief_height_mm = 2.500;
skirt_relief_z_mm = 3.000;
front_skirt_relief_centers_x_mm = [18.800, 38.700, 59.700];
back_skirt_relief_centers_x_mm = [18.800, 38.700, 59.700];
left_skirt_relief_width_mm = 1.800;
left_skirt_relief_depth_mm = 3.800;
left_skirt_relief_centers_y_mm = [15.000, 22.600, 30.200, 37.800];

// --- Preview colors (used only by debug/color-key render modes) ---
color_top_bezel_shell = "gold";
color_inner_cavity_cutout = "dodgerblue";
color_display_window_cutout = "limegreen";
color_side_control_slot_cutouts = "magenta";
color_corner_relief_hole_cutouts = "red";
color_skirt_alignment_relief_cutouts = "cyan";
color_source_mesh_overlay = "orange";

$fn = 64;

// ===========================================
// HELPERS
// ===========================================

module rounded_rect_2d(width_mm, depth_mm, radius_mm) {
    effective_radius_mm = min(radius_mm, min(width_mm, depth_mm) / 2);
    hull() {
        translate([effective_radius_mm, effective_radius_mm])
            circle(r = effective_radius_mm);
        translate([width_mm - effective_radius_mm, effective_radius_mm])
            circle(r = effective_radius_mm);
        translate([effective_radius_mm, depth_mm - effective_radius_mm])
            circle(r = effective_radius_mm);
        translate([width_mm - effective_radius_mm, depth_mm - effective_radius_mm])
            circle(r = effective_radius_mm);
    }
}

module rounded_box(width_mm, depth_mm, height_mm, radius_mm) {
    linear_extrude(height = height_mm)
        rounded_rect_2d(width_mm, depth_mm, radius_mm);
}

module rounded_slot_box(width_mm, depth_mm, height_mm, radius_mm) {
    linear_extrude(height = height_mm)
        rounded_rect_2d(width_mm, depth_mm, radius_mm);
}

// ===========================================
// POSITIVE GEOMETRY
// ===========================================

/**
 * Top Bezel Positive Shell
 *
 * POSITION:
 *   Origin: [0,0,0]
 *
 * BOUNDING BOX:
 *   Min: [0,0,0]
 *   Max: [76.2,49.523,15]
 *
 * ALIGNMENT:
 *   The normalized source mesh bounding-box minimum maps to this origin.
 *
 * CONNECTS TO:
 *   - ttgo_base_tray: lower skirt seats in the base tray rim.
 */
module top_bezel_positive_shell() {
    rounded_box(case_width_mm, case_depth_mm, top_bezel_height_mm,
                case_corner_radius_mm);
}

// ===========================================
// NEGATIVE CUTOUTS
// ===========================================

module top_bezel_negative_cutouts() {
    top_bezel_inner_cavity_cutout();
    top_bezel_display_window_cutout();
    top_bezel_side_control_slot_cutouts();
    top_bezel_corner_relief_hole_cutouts();
    top_bezel_skirt_alignment_relief_cutouts();
}

/**
 * Inner Cavity Cutout
 *
 * POSITION:
 *   Origin: [2.9,2.4,-0.05]
 *
 * BOUNDING BOX:
 *   Min: [2.9,2.4,-0.05]
 *   Max: [73.3,47.1,12.05]
 *
 * ALIGNMENT:
 *   Opens the underside while leaving the top face plate intact.
 *
 * CONNECTS TO:
 *   - base tray cavity through the mating skirt opening.
 */
module top_bezel_inner_cavity_cutout() {
    translate([top_bezel_inner_cavity_x_mm,
               top_bezel_inner_cavity_y_mm,
               -case_epsilon_mm])
        rounded_box(top_bezel_inner_cavity_width_mm,
                    top_bezel_inner_cavity_depth_mm,
                    top_bezel_inner_cavity_height_mm,
                    case_inner_corner_radius_mm);
}

/**
 * Display Window Cutout
 *
 * POSITION:
 *   Origin: [15.2,5.6,11.95]
 *
 * BOUNDING BOX:
 *   Min: [15.2,5.6,11.95]
 *   Max: [66.7,44.0,15.55]
 *
 * ALIGNMENT:
 *   Through-cut in the top face plate, measured from upper Z slices.
 *
 * CONNECTS TO:
 *   - display glass / visible screen area.
 */
module top_bezel_display_window_cutout() {
    translate([display_window_x_mm,
               display_window_y_mm,
               top_bezel_height_mm - top_bezel_face_thickness_mm - case_epsilon_mm])
        rounded_box(display_window_width_mm,
                    display_window_depth_mm,
                    top_bezel_face_thickness_mm + (2 * case_cut_overshoot_mm),
                    display_window_corner_radius_mm);
}

/**
 * Side Control Slot Cutouts
 *
 * POSITION:
 *   Four rounded rectangular openings near the left side of the top face.
 *
 * BOUNDING BOX:
 *   Each slot is approximately [8.7,5.9,thru].
 *
 * ALIGNMENT:
 *   Centers are spaced along Y using side_control_slot_pitch_mm.
 *
 * CONNECTS TO:
 *   - side button / speaker / finger-access region from the source mesh.
 */
module top_bezel_side_control_slot_cutouts() {
    for (slot_index = [0 : side_control_slot_count - 1]) {
        translate([side_control_slot_x_mm,
                   side_control_slot_first_y_mm + slot_index * side_control_slot_pitch_mm,
                   top_bezel_height_mm - top_bezel_face_thickness_mm - case_epsilon_mm])
            rounded_slot_box(side_control_slot_width_mm,
                             side_control_slot_depth_mm,
                             top_bezel_face_thickness_mm + (2 * case_cut_overshoot_mm),
                             side_control_slot_radius_mm);
    }
}
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

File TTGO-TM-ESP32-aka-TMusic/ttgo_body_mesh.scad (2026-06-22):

/**
 * TTGO-TM ESP32 ("TMusic") — FRONT BEZEL  [MESH / IMPORT WRAPPER]
 *
 * This file imports the original CATIA-exported STL mesh verbatim, so the
 * geometry is 100% faithful to the source part. Use this when you need an
 * exact reproduction (e.g. final print). For an editable, parametric
 * approximation of the same part, see ttgo_body.scad.
 *
 * Coordinate System (inherited from the source mesh — NOT the project corner
 * convention; the parametric file ttgo_body.scad uses the corner convention):
 *   X = Width  (positive = right)
 *   Y = Depth  (positive = back/away from viewer)
 *   Z = Height (positive = up)
 *
 * SOURCE MESH BOUNDING BOX (millimetres):
 *   Min:  [-36.675, -44.423, -3.540]
 *   Max:  [ 39.525,   5.100, 11.460]
 *   Size: [ 76.200,  49.523, 15.000]
 *
 * The mesh origin is roughly inside the part (CATIA digitised-shape origin),
 * not at a corner. debug_recenter() below shifts the part so its bounding-box
 * min sits at the origin if you prefer corner-origin coordinates.
 */

// ===========================================
// SOURCE FILE
// ===========================================
body_mesh_file = "ttgo-body-2.stl";   // must sit beside this .scad

// Bounding-box constants (from mesh analysis) — used by debug helpers.
body_mesh_min_mm  = [-36.675, -44.423, -3.540];
body_mesh_max_mm  = [ 39.525,   5.100, 11.460];
body_mesh_size_mm = [ 76.200,  49.523, 15.000];

// ===========================================
// PART
// ===========================================

/**
 * Front bezel, exactly as exported.
 * POSITION:     mesh-native (origin interior to part)
 * BOUNDING BOX: see body_mesh_min_mm / body_mesh_max_mm above
 */
module ttgo_body_mesh() {
    import(body_mesh_file, convexity = 10);
}

// ===========================================
// DEBUG / VISUALIZATION
// ===========================================

// Render coordinate axes at origin (length = 50mm).
module debug_axes(length = 50) {
    color("red")   cylinder(h = length, r = 1, $fn = 16);                 // Z
    color("green") rotate([0, 90, 0]) cylinder(h = length, r = 1, $fn = 16); // X
    color("blue")  rotate([-90, 0, 0]) cylinder(h = length, r = 1, $fn = 16); // Y
}

// Transparent bounding box of the imported mesh.
module debug_bounds() {
    color("yellow", 0.2)
        translate(body_mesh_min_mm)
            cube(body_mesh_size_mm);
}

// Same mesh, shifted so its bounding-box min sits at the origin
// (corner-origin convention used elsewhere in this project).
module debug_recenter() {
    translate(-body_mesh_min_mm)
        ttgo_body_mesh();
}

// ===========================================
// DEFAULT RENDER
// ===========================================
ttgo_body_mesh();

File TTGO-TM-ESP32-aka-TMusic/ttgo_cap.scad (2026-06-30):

/**
 * TTGO-TM ESP32 ("TMusic") - BASE TRAY
 * Parametric constructive rebuild from ttgo-cap-2.stl.
 *
 * The source file uses "cap", but the part is the deep base tray. This model
 * starts with the overall rounded bounding block, removes the main cavity and
 * rim rabbet as named negative cutouts, and adds discrete support/lug blocks
 * observed in high-Z mesh cross-sections.
 *
 * Coordinate System:
 *   X = Width  (positive = right)
 *   Y = Depth  (positive = back/away from viewer)
 *   Z = Height (positive = up)
 *
 * Origin: Front-left-bottom corner of the normalized tray bounding box.
 *
 * ===========================================
 * COMPONENT INDEX
 * ===========================================
 *
 * | Component                     | Preview Color | Origin [X,Y,Z] | Size [W,D,H]        | Attaches To      |
 * |-------------------------------|---------------|----------------|---------------------|------------------|
 * | base_tray_outer_block         | gold          | [0,0,0]        | [76.2,49.523,22.15] | ground / print   |
 * | base_tray_inner_cavity        | dodgerblue    | [5.25,4.25,1.75]| [66.7,41.0,thru]   | negative cutout  |
 * | base_tray_rim_rabbet          | limegreen     | top perimeter  | 5.4 high            | bezel skirt      |
 * | support_lugs (x4)             | magenta       | inner rim      | variable            | PCB / latch area |
 * | snap_tabs                     | cyan          | rim lip        | variable            | bezel reliefs    |
 * | left_wall_connector_reliefs   | red           | left wall      | variable            | negative cutout  |
 */

// ===========================================
// DIMENSIONS (all values in millimeters)
// ===========================================

// --- Source mesh facts ---
source_cap_mesh_file = "ttgo-cap-2.stl";
source_cap_bbox_min_mm = [-36.675, -44.4235, -20.290];
source_cap_bbox_max_mm = [ 39.525,   5.1000,   1.860];
source_cap_bbox_size_mm = [76.200, 49.5235, 22.150];
source_cap_face_count = 54112;

// --- Global / shared case dimensions ---
case_width_mm = 76.200;
case_depth_mm = 49.523;
case_corner_radius_mm = 2.300;
case_inner_corner_radius_mm = 0.800;
case_wall_thickness_mm = 2.500;
case_fit_clearance_xy_mm = 0.250;
case_fit_clearance_z_mm = 0.200;
case_epsilon_mm = 0.050;
case_cut_overshoot_mm = 0.500;

// --- base_tray_outer_block dimensions ---
base_tray_height_mm = 22.150;
base_tray_floor_thickness_mm = 1.750;

// --- base_tray_inner_cavity_cutout dimensions ---
base_tray_inner_cavity_x_mm = 5.250;
base_tray_inner_cavity_y_mm = 4.250;
base_tray_inner_cavity_width_mm = 66.700;
base_tray_inner_cavity_depth_mm = 41.000;

// --- base_tray_rim_rabbet_cutout dimensions ---
base_tray_rim_height_mm = 5.400;
base_tray_rim_inset_x_mm = 3.700;
base_tray_rim_inset_y_mm = 2.700;
base_tray_rim_width_mm = 69.800;
base_tray_rim_depth_mm = 44.100;
base_tray_rim_corner_radius_mm = 1.600;

// --- support_lugs dimensions ---
support_lug_height_mm = 3.300;
support_lug_z_mm = 18.100;
support_lug_depth_mm = 2.200;
support_lug_corner_radius_mm = 0.400;
front_support_lug_specs_mm = [
    [13.800, 14.200],
    [49.000, 14.200]
];
rear_support_lug_specs_mm = [
    [23.800,  6.400],
    [56.000,  8.500]
];

// --- left_wall_connector_relief_cutouts dimensions ---
left_wall_relief_x_mm = -case_epsilon_mm;
left_wall_relief_width_mm = 4.000;
left_wall_relief_height_mm = 8.500;
left_wall_relief_z_mm = base_tray_height_mm - left_wall_relief_height_mm;
left_wall_relief_depth_mm = 7.200;
left_wall_relief_centers_y_mm = [18.200, 36.800];

// --- snap_tabs dimensions (positive tabs matching bezel inside-wall reliefs) ---
snap_tab_clearance_xy_mm = 0.150;
snap_tab_clearance_z_mm = 0.150;
snap_tab_relief_z_from_bezel_bottom_mm = 3.000;
snap_tab_z_mm = base_tray_height_mm - base_tray_rim_height_mm + snap_tab_relief_z_from_bezel_bottom_mm;
snap_tab_height_mm = min(2.500 - snap_tab_clearance_z_mm,
                         base_tray_height_mm - snap_tab_z_mm - case_epsilon_mm);
snap_tab_width_mm = 8.000 - 2 * snap_tab_clearance_xy_mm;
snap_tab_depth_mm = 1.400 - snap_tab_clearance_xy_mm;
snap_tab_front_centers_x_mm = [18.800, 38.700, 59.700];
snap_tab_back_centers_x_mm = [18.800, 38.700, 59.700];
snap_tab_left_width_mm = 1.800 - snap_tab_clearance_xy_mm;
snap_tab_left_depth_mm = 3.800 - 2 * snap_tab_clearance_xy_mm;
snap_tab_left_centers_y_mm = [15.000, 22.600, 30.200, 37.800];

// --- Preview colors (used only by debug/color-key render modes) ---
color_base_tray_outer_block = "gold";
color_inner_cavity_cutout = "dodgerblue";
color_rim_rabbet_cutout = "limegreen";
color_support_lugs = "magenta";
color_snap_tabs = "cyan";
color_left_wall_connector_reliefs = "red";
color_source_mesh_overlay = "orange";

$fn = 64;

// ===========================================
// HELPERS
// ===========================================

module rounded_rect_2d(width_mm, depth_mm, radius_mm) {
    effective_radius_mm = min(radius_mm, min(width_mm, depth_mm) / 2);
    hull() {
        translate([effective_radius_mm, effective_radius_mm])
            circle(r = effective_radius_mm);
        translate([width_mm - effective_radius_mm, effective_radius_mm])
            circle(r = effective_radius_mm);
        translate([effective_radius_mm, depth_mm - effective_radius_mm])
            circle(r = effective_radius_mm);
        translate([width_mm - effective_radius_mm, depth_mm - effective_radius_mm])
            circle(r = effective_radius_mm);
    }
}

module rounded_box(width_mm, depth_mm, height_mm, radius_mm) {
    linear_extrude(height = height_mm)
        rounded_rect_2d(width_mm, depth_mm, radius_mm);
}

// ===========================================
// POSITIVE GEOMETRY
// ===========================================

/**
 * Base Tray Outer Block
 *
 * POSITION:
 *   Origin: [0,0,0]
 *
 * BOUNDING BOX:
 *   Min: [0,0,0]
 *   Max: [76.2,49.523,22.15]
 *
 * ALIGNMENT:
 *   The normalized source mesh bounding-box minimum maps to this origin.
 *
 * CONNECTS TO:
 *   - top bezel skirt through the rim rabbet.
 */
module base_tray_outer_block() {
    rounded_box(case_width_mm, case_depth_mm, base_tray_height_mm,
                case_corner_radius_mm);
}

/**
 * Base Tray Support Lugs
 *
 * POSITION:
 *   Four discrete raised blocks near the upper inner rim.
 *
 * BOUNDING BOX:
 *   z range: [18.1,21.4].
 *
 * ALIGNMENT:
 *   The blocks are added after the cavity/rabbet are cut so they remain as
 *   functional pads inside the tray.
 *
 * CONNECTS TO:
 *   - PCB edge / bezel latch region inferred from source sections.
 */
module base_tray_support_lugs_positive() {
    for (lug_spec = front_support_lug_specs_mm) {
        translate([lug_spec[0],
                   base_tray_inner_cavity_y_mm - support_lug_depth_mm,
                   support_lug_z_mm])
            rounded_box(lug_spec[1],
                        support_lug_depth_mm,
                        support_lug_height_mm,
                        support_lug_corner_radius_mm);
    }

    for (lug_spec = rear_support_lug_specs_mm) {
        translate([lug_spec[0],
                   base_tray_inner_cavity_y_mm + base_tray_inner_cavity_depth_mm,
                   support_lug_z_mm])
            rounded_box(lug_spec[1],
                        support_lug_depth_mm,
                        support_lug_height_mm,
                        support_lug_corner_radius_mm);
    }
}

/**
 * Base Tray Snap Tabs
 *
 * POSITION:
 *   Positive tabs on the upper rim lip, aligned with the bezel's inside-wall
 *   skirt relief pockets.
 *
 * BOUNDING BOX:
 *   z range starts at snap_tab_z_mm, which places the tabs 3 mm above the
 *   seated bezel bottom.
 *
 * ALIGNMENT:
 *   Front/back tabs protrude outward from the tray rim lip. Left-side tabs
 *   protrude outward from the left rim lip. A small clearance is applied so the
 *   tabs fit into the bezel pockets instead of being the exact same size.
 *
 * CONNECTS TO:
 *   - top_bezel_skirt_alignment_relief_cutouts in ttgo_body.scad.
 */
module base_tray_snap_tabs_positive() {
    for (center_x_mm = snap_tab_front_centers_x_mm)
        translate([center_x_mm - snap_tab_width_mm / 2,
                   base_tray_rim_inset_y_mm - snap_tab_depth_mm,
                   snap_tab_z_mm])
            cube([snap_tab_width_mm,
                  snap_tab_depth_mm + case_epsilon_mm,
                  snap_tab_height_mm]);

    for (center_x_mm = snap_tab_back_centers_x_mm)
        translate([center_x_mm - snap_tab_width_mm / 2,
                   base_tray_rim_inset_y_mm + base_tray_rim_depth_mm - case_epsilon_mm,
                   snap_tab_z_mm])
            cube([snap_tab_width_mm,
                  snap_tab_depth_mm + case_epsilon_mm,
                  snap_tab_height_mm]);
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

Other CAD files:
TTGO-TM-ESP32-aka-TMusic/ttgo_cap_mesh.scad
tools/draw2d.scad
tools/view3d.scad

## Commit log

2026-06-22 Add TTGO-TM ESP32 (TMusic) enclosure: parametric + mesh SCAD
    Create TTGO-TM-ESP32-aka-TMusic/ with both forms of each part, built from
    the source meshes ttgo-body-2.stl (front bezel) and ttgo-cap-2.stl (base tray):
    - *_mesh.scad: import the original CATIA STL verbatim (geometry-exact)
    - ttgo_body.scad / ttgo_cap.scad: editable parametric rebuilds (approximate),
    following the project OpenSCAD conventions (named dims, modules, debug,
    connection interfaces, per-file .md docs)
    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
    [ttgo-body-2.stl, ttgo-cap-2.stl, ttgo_body.scad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]
2026-06-22 Add dimensioned drawing diagrams + wire into build pipeline
    Add tools/ that generate engineering drawing sheets for each case component:
    - tools/draw2d.scad: 2D projection line-art views (front/top/right); elevation
    views project a thin wall slab so face features (e.g. bezel side ports) show
    - tools/view3d.scad: shaded isometric panel
    - tools/make_drawings.py: renders the views via OpenSCAD and composes a
    dimensioned multi-view sheet (overall + detail dimension leaders, button/
    window callouts, title block, detail-dimensions table) per part
    Pipeline integration:
    - build.sh/build.bat now emit *_drawing.png after the STL/PNG pass (skips the
    tools/ wrappers; skips drawings gracefully i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
    [draw2d.scad, view3d.scad]
2026-06-30 Rebuild TTGO enclosure from STL sections
    [ttgo_body.scad, ttgo_cap.scad]
2026-06-30 Add TTGO color key previews
    [ttgo_body.scad, ttgo_cap.scad]
2026-06-30 Clarify TTGO color key view mode
    [ttgo_body.scad, ttgo_cap.scad]
2026-06-30 Default TTGO previews to color view
    [ttgo_body.scad, ttgo_cap.scad]
2026-06-30 Move TTGO bezel reliefs inside walls
    [ttgo_body.scad]
2026-06-30 Add TTGO snap tabs and raised relief pockets
    [ttgo_body.scad, ttgo_cap.scad]
